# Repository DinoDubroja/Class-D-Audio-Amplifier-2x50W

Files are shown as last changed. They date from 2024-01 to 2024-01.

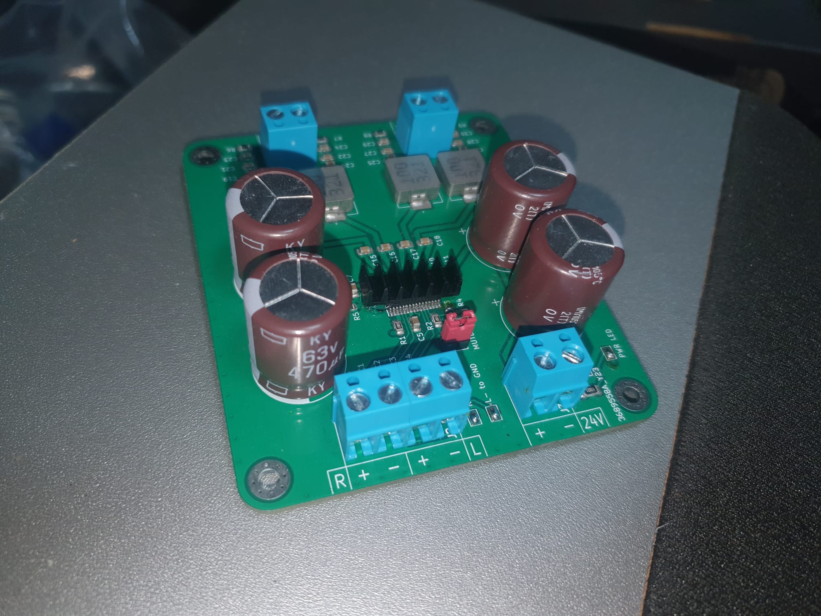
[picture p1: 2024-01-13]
Board.jpeg

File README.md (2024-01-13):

# Class-D-Audio-Amplifier-2x50W

High-quality stereo class D audio amplifier (2x50W). The board is based on Texas Instruments TPA3118D2 (Class D amplifier IC). Adding a heatsink to the IC is necessary to fully utilize this board's power capabilities. 

All parts I used are listed in BOM and part numbers for Mouser Electronics are provided. Values of filter capacitors can be changed to optimize t for subwoofer operation. If you want to do this please refer to the datasheet of the IC and application circuit provided.

Board

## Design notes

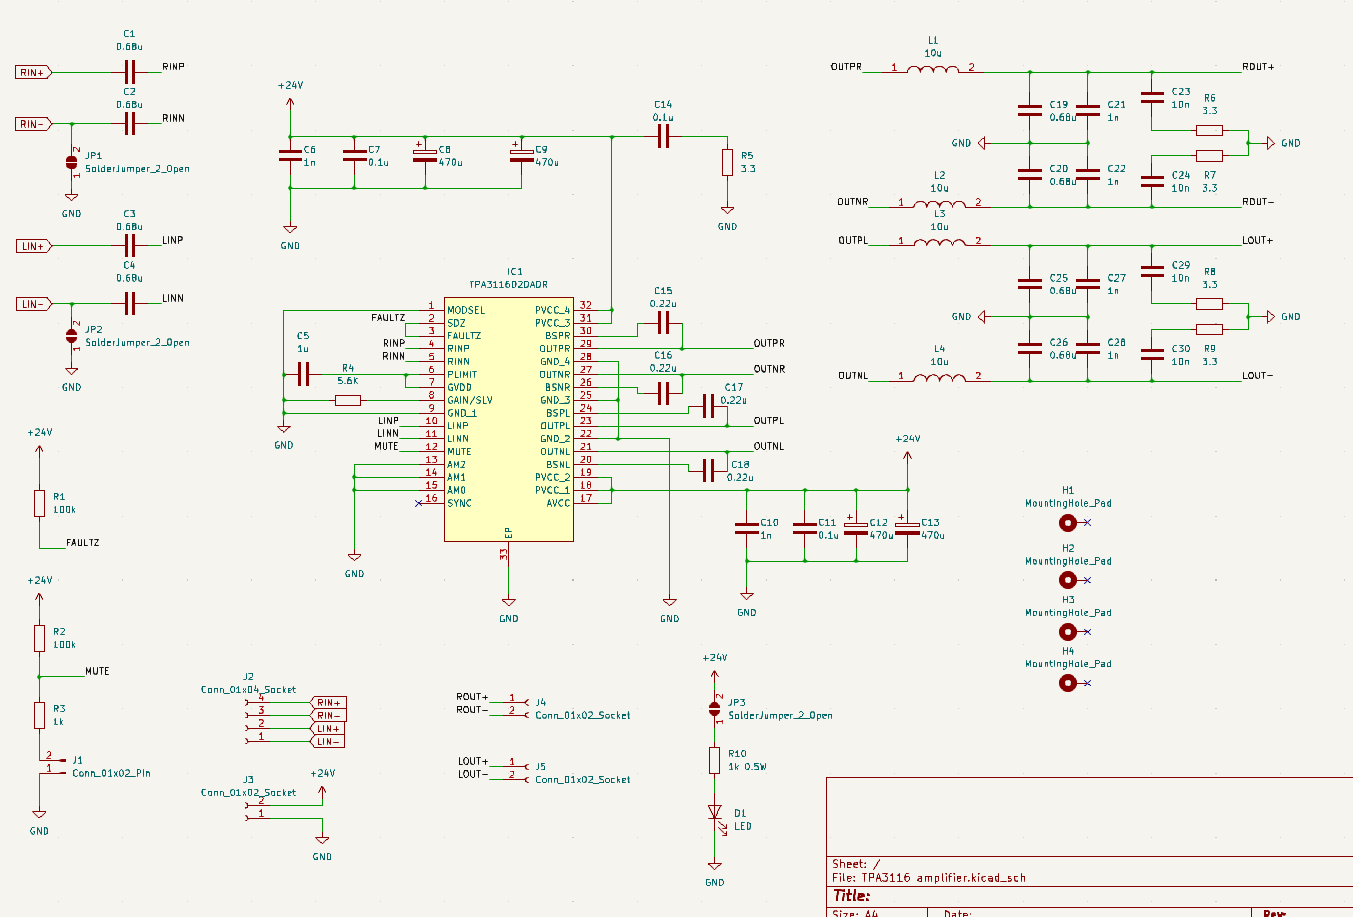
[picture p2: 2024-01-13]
Schematic.png

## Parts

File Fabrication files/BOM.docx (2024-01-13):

PART NO. (MOUSER) | Component description | Reference | Component value | Footprint & ratings
81-GCM21BR71E684KA5L | Capacitor | C1,C2,C3,C4, C19,C20,C25,C26 | 0.68u | X7R, 25v, 10%, 0805
81-GCM216R71H102KA7D | Capacitor | C6,C10,C21,C22 C27,C28 | 1n | X7R, 50V, 10%, 0805
81-GCM21BR71E105KA6K | Capacitor | C5 | 1u | X7R,25V, 10%, 0805
81-GCE21BR71H104KA1L | Capacitor | C7,C11,C15 | 0.1u | X7R, 50V, 10%, 0805
661-EKY63ELL471ML20S | Capacitor | C8,C9,C12,C13 | 470u | 63v, 20%, 10000h, 105°C (16x20)
81-GRM21R71E224KA01D | Capacitor | C15,C16,C17,C18 | 0.22u | 25V, X7R, 10%, 0805
81-GCM219R71H103KA7D | Capacitor | C23,C24,C29,C30 | 10n | 50v, X7R, 10%, 0805
652-CR0805AFX1003ELF | Resistor | R1,R2 | 100k | 1%, 0805
652-CHP1206FX1001ELF | Resistor | R3, R10 | 1k | 1% 3/4W, 1206
652-CR0805FX-5601ELF | Resistor | R4 | 5.6k | 1%, 0805
71-CRCW08053R30FKEA | Resistor | R5,R6,R7,R8,R9 | 3.3 | 0805
851-104CDMCCDS-100MC | Inductor | L1,L2,L3,L4 | 10u
595-TPA3116D2DADR | Amplifier IC | U1
490-TB001-500-04BE | Connector | | 4pin 5mm pitch | Screw terminal
490-TB001-500-02BE | Connector | | 2pin 5mm pitch | Screw terminal

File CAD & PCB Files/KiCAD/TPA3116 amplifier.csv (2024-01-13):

Source: | C:\Users\dinod\OneDrive\Documents\KiCad\TPA3116 amplifier\TPA3116 amplifier.kicad_sch
Date: | 1.10.2023. 15:49:13
Tool: | Eeschema 7.0.6
Generator: | C:\Program Files\KiCad\7.0\bin\scripting\plugins/bom_csv_grouped_by_value.py
Component Count: | 46
Collated Components:
Item | Qty | Reference(s) | Value | LibPart | Footprint | Datasheet | DNP | Height | Manufacturer_Name | Manufacturer_Part_Number | Mouser Part Number | Mouser Price/Stock
1 | 4 | C1, C2, C3, C4 | 0.68 | Device:C |  | ~
2 | 6 | C5, C10, C21, C22, C27, C29 | 1n | Device:C |  | ~
3 | 3 | C6, C11, C14 | 0.1u | Device:C |  | ~
4 | 2 | C7, C8 | 470u | Device:C |  | ~
5 | 1 | C9 | 1u | Device:C |  | ~
6 | 2 | C12, C13 | 470u | Device:C_Polarized |  | ~
7 | 4 | C15, C16, C17, C18 | 0.22 | Device:C |  | ~
8 | 4 | C19, C20, C26, C28 | 0.68u | Device:C |  | ~
9 | 4 | C23, C24, C25, C30 | 10n | Device:C |  | ~
10 | 1 | IC1 | TPA3116D2DADR | SamacSys_Parts:TPA3116D2DADR | SOP65P810X120-33N | http://www.ti.com/lit/gpn/tpa3116d2 |  | 1.2 | Texas Instruments | TPA3116D2DADR | 595-TPA3116D2DADR | https://www.mouser.co.uk/ProductDetail/Texas-Instruments/TPA3116D2DADR?qs=3AcK5DacLbpIP1YDOj0hAg%3D%3D
11 | 1 | J1 | Conn_01x02_Pin | Connector:Conn_01x02_Pin |  | ~
12 | 1 | JP1 | SolderJumper_2_Open | Jumper:SolderJumper_2_Open |  | ~
13 | 4 | L1, L2, L3, L4 | 10u | Device:L |  | ~
14 | 1 | R1 | 5.6K | Device:R |  | ~
15 | 2 | R2, R3 | 100k | Device:R |  | ~
16 | 1 | R4 | 1k | Device:R |  | ~
17 | 5 | R5, R6, R7, R8, R9 | 3.3 | Device:R |  | ~

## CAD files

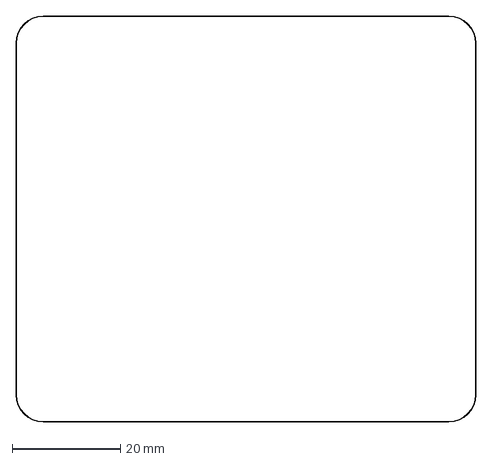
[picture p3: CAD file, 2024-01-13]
CAD & PCB Files/BoardOutline.dxf
85.0 x 75.0 mm

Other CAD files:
CAD & PCB Files/BoardOutline.dwg

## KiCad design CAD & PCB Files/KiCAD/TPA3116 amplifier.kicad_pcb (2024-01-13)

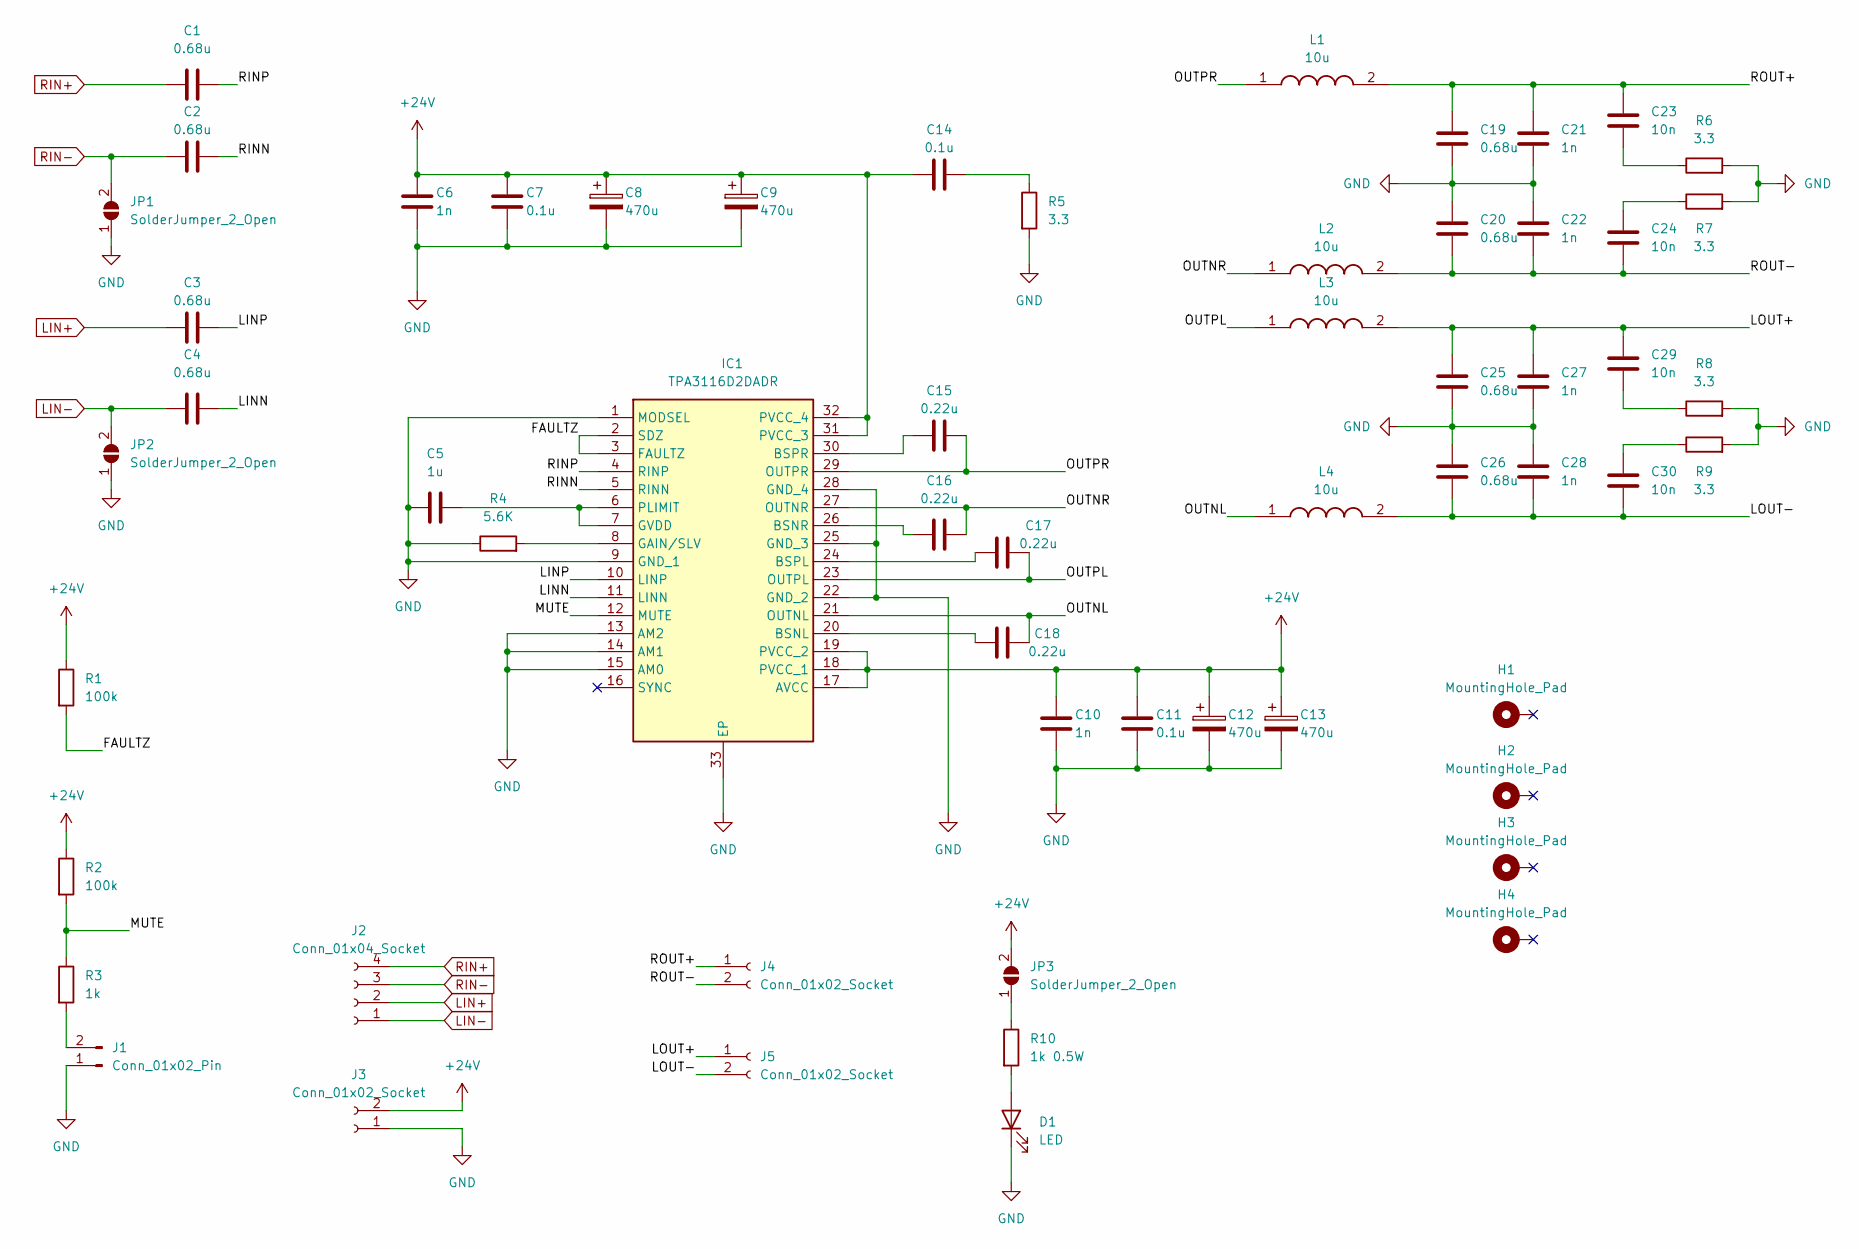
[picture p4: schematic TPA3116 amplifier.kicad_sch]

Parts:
C1, C2, C3, C4, C19, C20, C25, C26: 0.68u; C_0805_2012Metric_Pad1.18x1.45mm_HandSolder
C5: 1u; C_0805_2012Metric_Pad1.18x1.45mm_HandSolder
C6, C10, C21, C22, C27, C28: 1n; C_0805_2012Metric_Pad1.18x1.45mm_HandSolder
C7, C11, C14: 0.1u; C_0805_2012Metric_Pad1.18x1.45mm_HandSolder
C8, C9, C12, C13: 470u; CP_Radial_D16.0mm_P7.50mm
C15, C16, C17, C18: 0.22u; C_0805_2012Metric_Pad1.18x1.45mm_HandSolder
C23, C24, C29, C30: 10n; C_0805_2012Metric_Pad1.18x1.45mm_HandSolder
D1: LED; LED_1206_3216Metric
H1, H2, H3, H4: MountingHole_Pad; MountingHole_3.2mm_M3_Pad_Via
IC1: TPA3116D2DADR; SOP65P810X120-33N; Mouser Part Number 595-TPA3116D2DADR
J1: Conn_01x02_Pin; PinSocket_1x02_P2.54mm_Vertical
J2: Conn_01x04_Socket; TB00150004BE
J3, J4, J5: Conn_01x02_Socket; TB00150002BE
JP1, JP2, JP3: SolderJumper_2_Open; SolderJumper-2_P1.3mm_Open_TrianglePad1.0x1.5mm
L1, L2, L3, L4: 10u; 104CDMCCDS100MC; Mouser Part Number 851-104CDMCCDS-100MC
R1, R2: 100k; R_0805_2012Metric_Pad1.20x1.40mm_HandSolder
R3: 1k; R_0805_2012Metric_Pad1.20x1.40mm_HandSolder
R4: 5.6K; R_0805_2012Metric_Pad1.20x1.40mm_HandSolder
R5, R6, R7, R8, R9: 3.3; R_0805_2012Metric_Pad1.20x1.40mm_HandSolder
R10: 1k 0.5W; R_1206_3216Metric_Pad1.30x1.75mm_HandSolder

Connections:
+24V: C6.2, C7.2, C8.1, C9.1, C10.2, C11.2, C12.1, C13.1, C14.1, IC1.17 (AVCC), IC1.18 (PVCC_1), IC1.19 (PVCC_2), IC1.31 (PVCC_3), IC1.32 (PVCC_4), J3.2, JP3.2 (B), R1.1, R2.1
/FAULTZ: IC1.2 (SDZ), IC1.3 (FAULTZ), R1.2
/LINN: C4.2, IC1.11 (LINN)
/LINP: C3.2, IC1.10 (LINP)
/LOUT+: C25.1, C27.1, C29.1, J5.1, L3.2
/LOUT-: C26.2, C28.2, C30.2, J5.2, L4.2
/MUTE: IC1.12 (MUTE), R2.2, R3.1
/OUTNL: C18.2, IC1.21 (OUTNL), L4.1
/OUTNR: C16.2, IC1.27 (OUTNR), L2.1
/OUTPL: C17.2, IC1.23 (OUTPL), L3.1
/OUTPR: C15.2, IC1.29 (OUTPR), L1.1
/RINN: C2.2, IC1.5 (RINN)
/RINP: C1.2, IC1.4 (RINP)
/ROUT+: C19.1, C21.1, C23.1, J4.1, L1.2
/ROUT-: C20.2, C22.2, C24.2, J4.2, L2.2
GND: C5.2, C6.1, C7.1, C8.2, C9.2, C10.1, C11.1, C12.2, C13.2, C19.2, C20.1, C21.2, C22.1, C25.2, C26.1, C27.2, C28.1, D1.1 (K), IC1.1 (MODSEL), IC1.9 (GND_1), IC1.13 (AM2), IC1.14 (AM1), IC1.15 (AM0), IC1.22 (GND_2), IC1.25 (GND_3), IC1.28 (GND_4), IC1.33 (EP), J1.1, J3.1, JP1.1 (A), JP2.1 (A), R4.1, R5.2, R6.2, R7.2, R8.2, R9.2
LIN+: C3.1, J2.2
LIN-: C4.1, J2.1, JP2.2 (B)
unnamed: C14.2, R5.1
unnamed: C23.2, R6.1
unnamed: C24.1, R7.1
unnamed: C29.2, R8.1
unnamed: C30.1, R9.1
unnamed: D1.2 (A), R10.2
unnamed: C18.1, IC1.20 (BSNL)
unnamed: C16.1, IC1.26 (BSNR)
unnamed: C17.1, IC1.24 (BSPL)
unnamed: C15.1, IC1.30 (BSPR)
unnamed: IC1.8 (GAIN/SLV), R4.2
unnamed: C5.1, IC1.6 (PLIMIT), IC1.7 (GVDD)
unnamed: J1.2, R3.2
unnamed: JP3.1 (A), R10.1
RIN+: C1.1, J2.4
RIN-: C2.1, J2.3, JP1.2 (B)

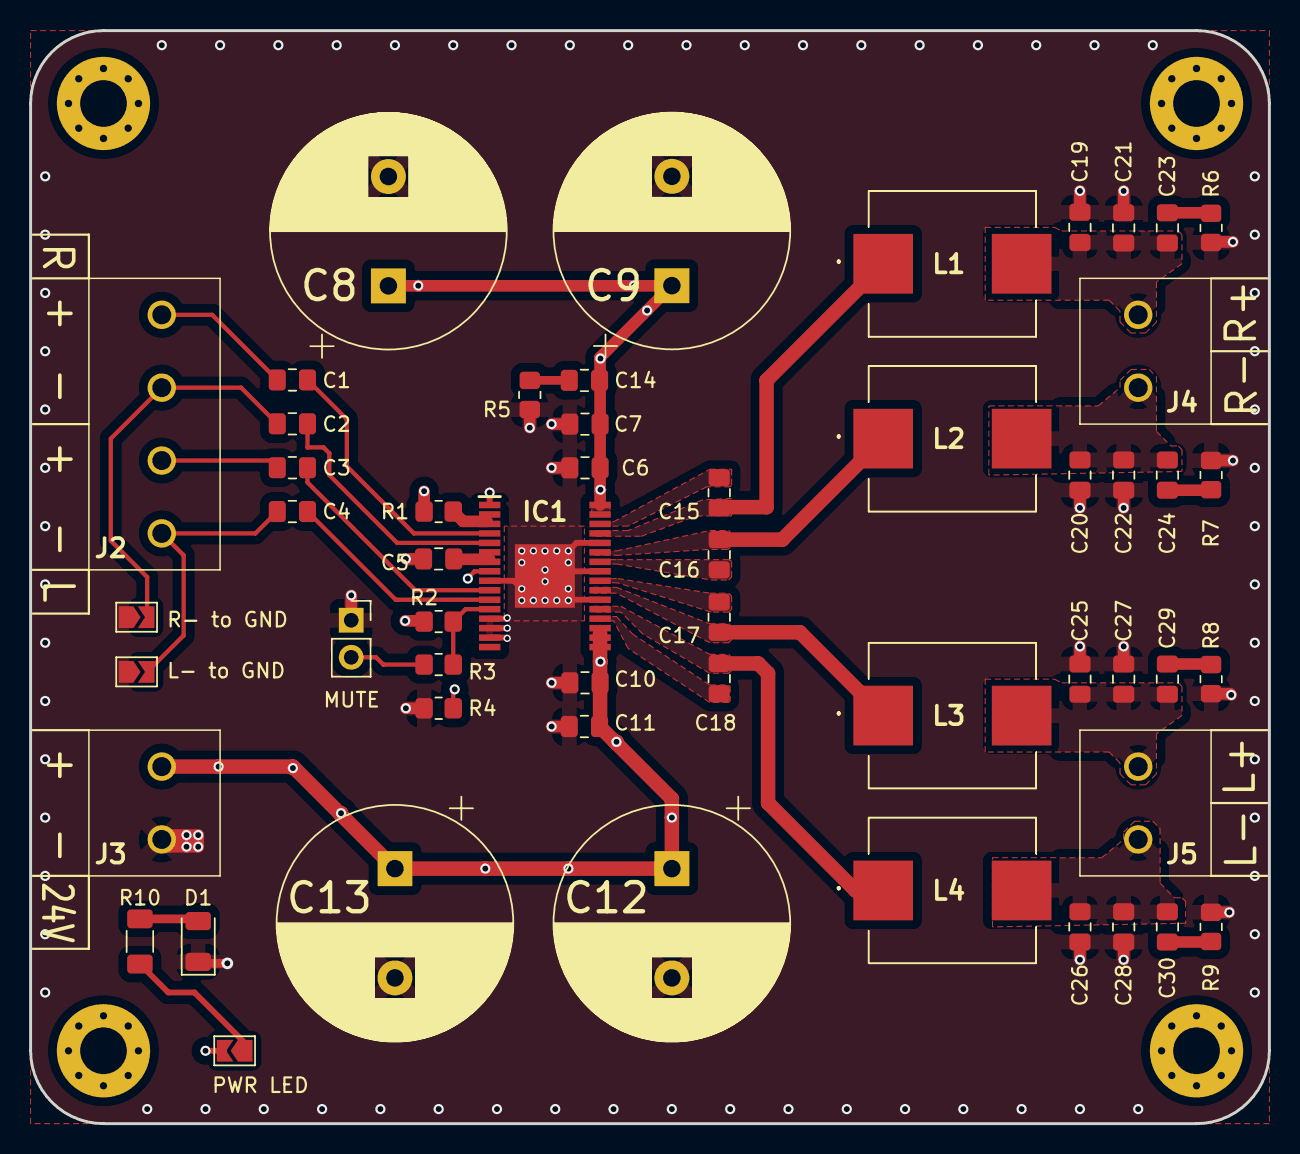
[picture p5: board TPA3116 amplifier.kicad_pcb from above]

Board: 4 copper layers, 85.0 x 75.0 mm, 58 parts (0 on the bottom side), 34 nets.
